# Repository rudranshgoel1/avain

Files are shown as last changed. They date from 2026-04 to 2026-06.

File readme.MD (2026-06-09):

# Avain
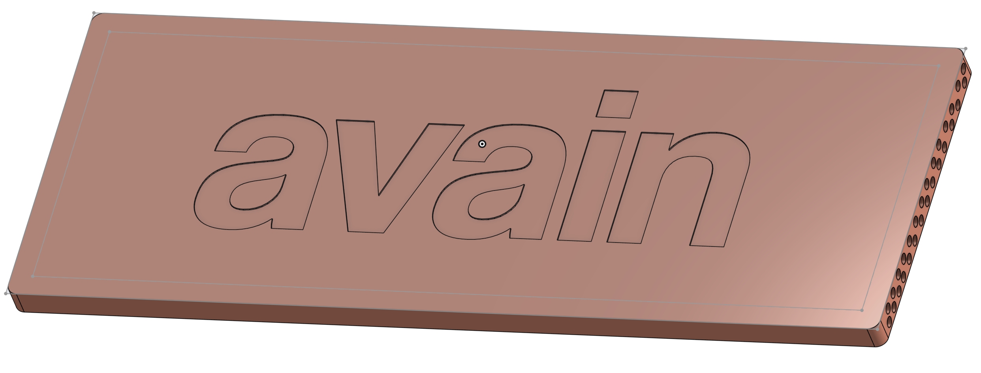
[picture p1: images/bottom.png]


### Why did I make it?
No specific reason tbh. But, another keyboard I made ([Clavis](https://github.com/rudranshgoel1/clavis)) was a 60%, I lowk wanted an 80% keyboard so I made it.

### What was the hardest part about this ?
Hardest part was actually finding time to make this.

Features:

- RotaryEncoder for Volume Control
- 87 keys (Base + Fn keys + arrow keys + 6 extra keys for home/pg up down and other)
- Raspberry Pi Pico
- Customised layout
- KMK firmware
- Avain Branded PCB
- Custom case

### Schematic
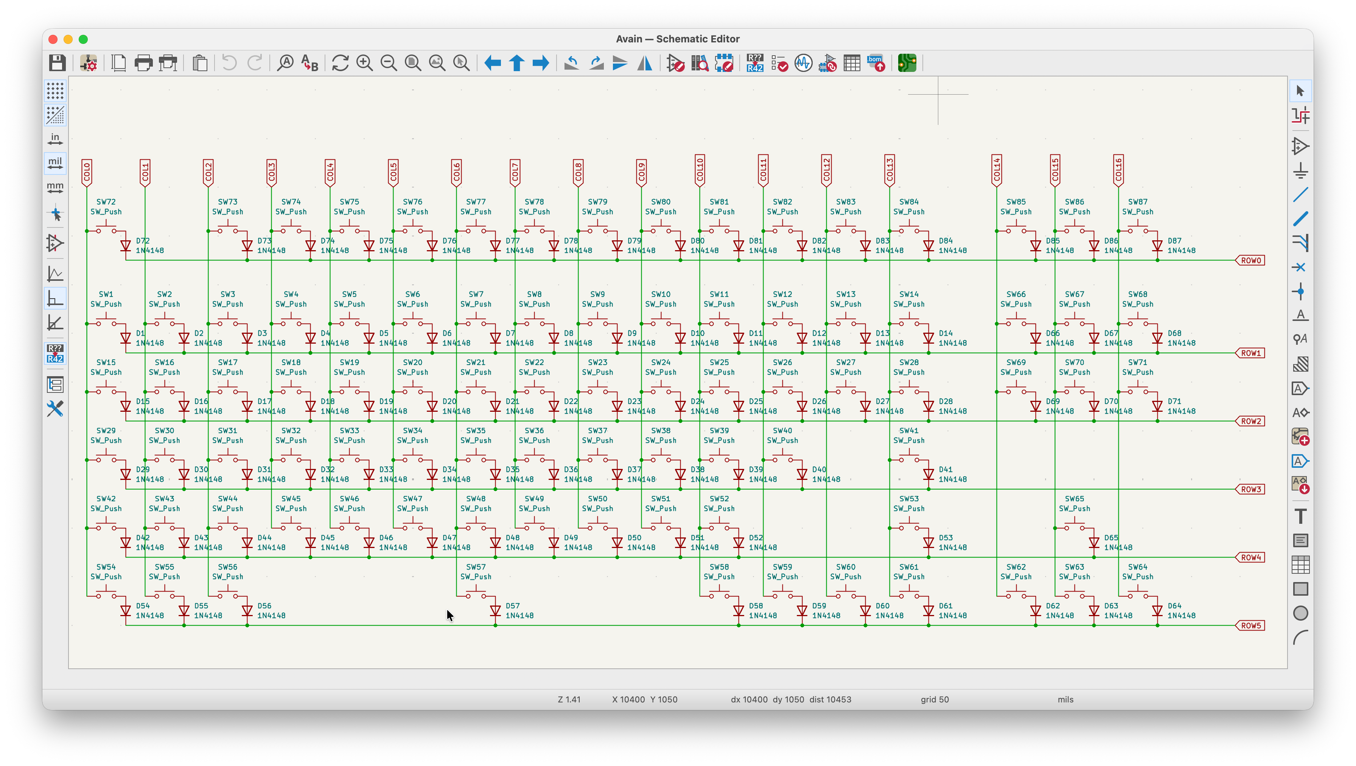
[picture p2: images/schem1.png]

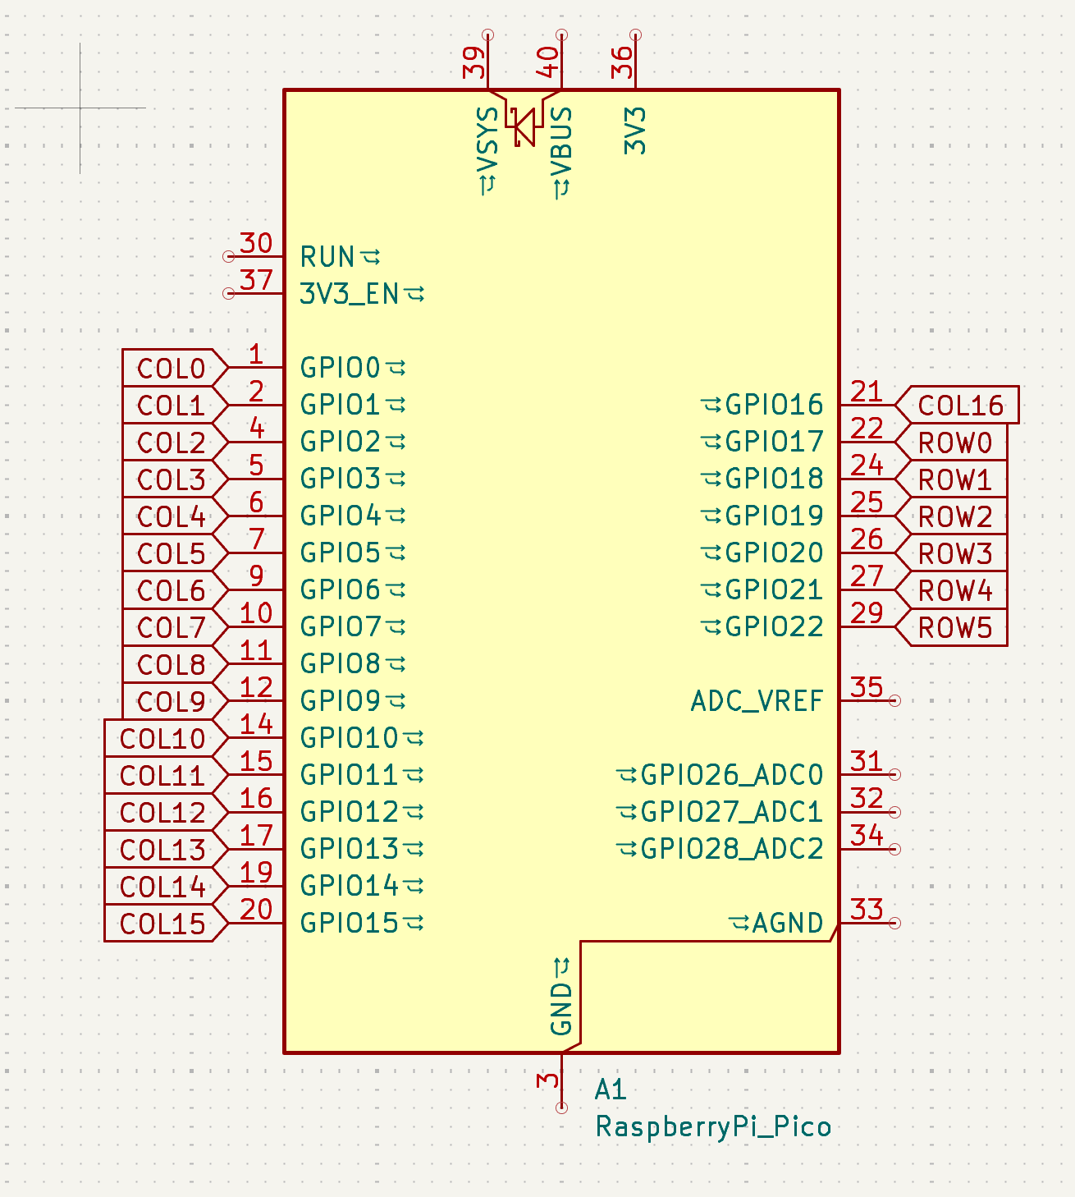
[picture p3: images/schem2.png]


### PCB 
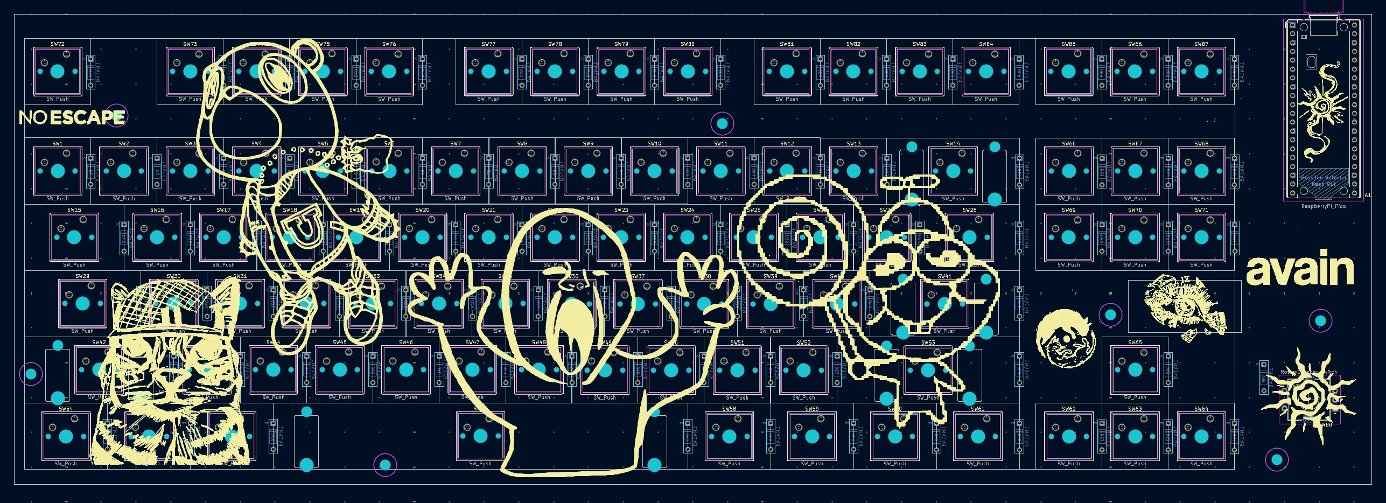
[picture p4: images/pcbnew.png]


### Case



- Side

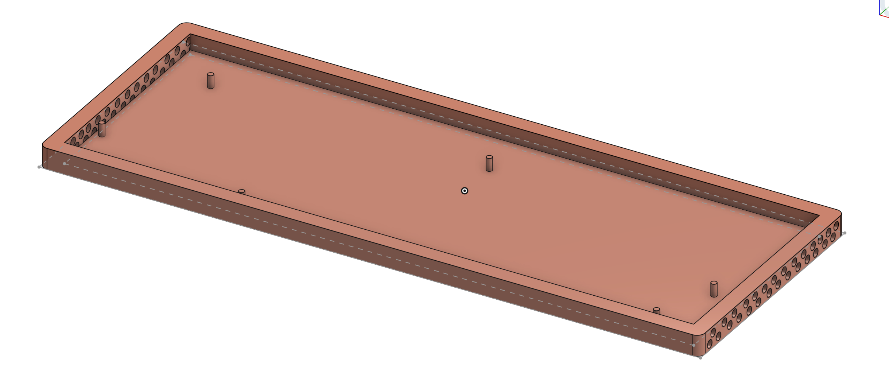
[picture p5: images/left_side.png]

I made some aesthetic for Avain. Like I have added holes on all the sides to make it look more good

### 3D view of all parts 
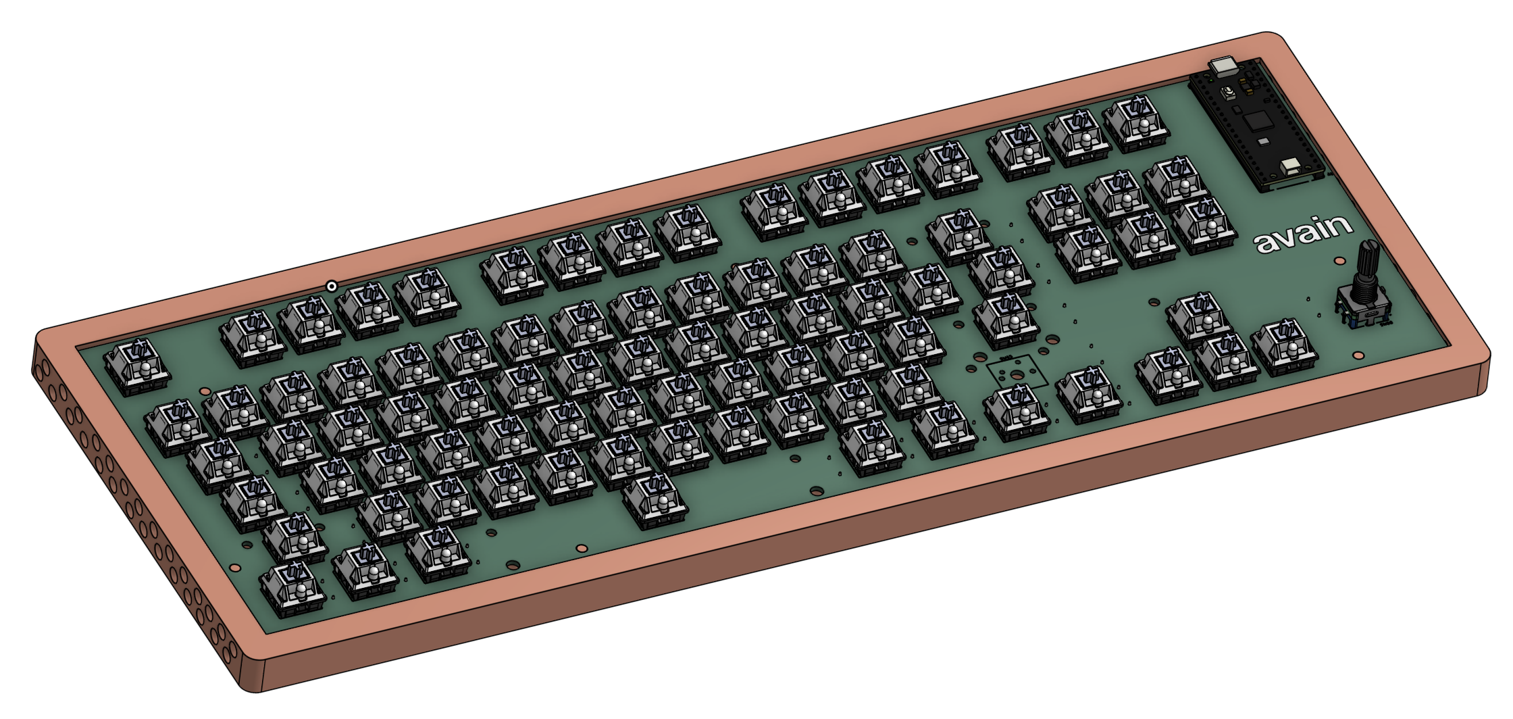
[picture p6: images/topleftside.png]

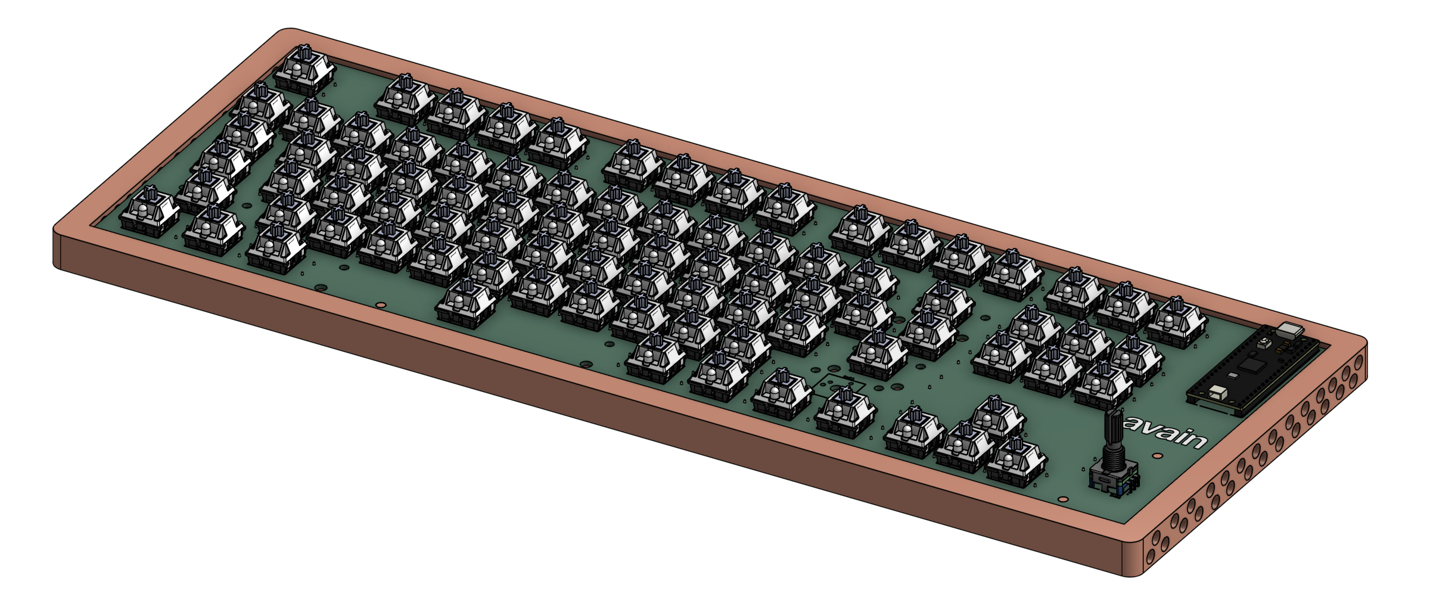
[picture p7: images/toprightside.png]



link to full 3d thing-
https://cad.onshape.com/documents/6774359217ff8c97b90facb7/w/2137304fb52ca582983570b9/e/130904d3ca2552892ee4c097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

A special thanks to Anay and Aditya ( once again ) who are helping me still to make my projects better. Love them so much!

|Name |Purpose |Quantity|Total Cost (INR)|Total Cost (USD)|Link |Distributor |
|---|---|---|---|---|---|---|
|Akko Creamy Cyan Switch |Switches for the keyboard |87 |₹2,598.00 |$28.06 |https://stackskb.com/store/akko-creamy-cyan-switch-pack-of-45-pre-order/ |StacksKB |
|Black Gray Yellow Cherry Doubleshot PBT Keycaps |Keycaps for the keyboard |1 |₹1,399.00 |$15.11 |https://curiositycaps.in/products/black-gray-yellow-cherry-doubleshot-pbt-keycaps|Curiosity Caps|
|Durock Smokey Screw-In Stabilizers V2 (4+1 w/ 6.25u spacebar)|Stabilizers for longer keys |1 |₹1,595.00 |$17.22 |https://stackskb.com/store/durock-smokey-screw-in-stabilizers-v2/ |StacksKB |
|EC11 10K Rotary Encoder |RotaryEncoder for Volume Control|1 |N/A |N/A |Self Sourced |Amazon |
|Raspberry Pi Pico |MCU for the keyboard |1 |₹859.00 |$9.01 |https://www.amazon.in/gp/product/B08WPNM7JB |Amazon |
|1N4148 Diodes |Diodes for the switches |1 |₹149.00 |$1.61 |https://www.amazon.in/gp/product/B084ZP5BJ3 |Amazon |
|PCB |Main PCB of the keyboard |5 |₹3,268.47 |$34.23 |https://jlcpcb.com/ |JLCPCB |
|Case |Case for the keyboard |1 |₹500.00 |$5.40 |Print Legion |Print Legion  |
| | | | | | | |
| | | | | | | |
| | | |₹10,368.47 |109.03 | | |

## Shipping
Amazon + StacksKB = ~$3
Printing Legion = ~$5

Total Shipping = $8

## Total Pricing
The total price comes out to be 10,368.47 INR ($109.03)
Total Shipping = $8

Price After Shipping - 11,175 INR ($117.03)

The pricing might slightly vary due to flash sales, and dollar market trends.

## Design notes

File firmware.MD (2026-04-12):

## Flashing and Configuring the Keyboard

Steps to install the firmware and configure the keyboard:

### 1. Downloading the Repository
Download or clone this repository to your computer.
https://github.com/rudranshgoel1/avain.git

### 2. Enter Boot Mode on the Pico
1. Unplug the Raspberry Pi Pico from your computer.
2. Hold down the **BOOTSEL** button on the Pico.
3. While holding the button, plug the Pico into your computer using a USB cable.
4. The computer will detect a new drive named **RPI-RP2**.

### 3. Flash CircuitPython
1. Download the latest CircuitPython `.uf2` for the Raspberry Pi Pico from [circuitpython.org](https://circuitpython.org/board/raspberry_pi_pico/).
2. Drag and drop the `.uf2` file onto the **RPI-RP2** drive.

Once the file finishes copying, the Pico will reboot automatically and appear as a new drive named **CIRCUITPY**.

### 4. Install KMK and the Keymap
1. Download KMK from [kmkfw.io](https://kmkfw.io) and copy the `kmk/` folder to the root of **CIRCUITPY**.
2. Copy `main.py` from this repository to the root of **CIRCUITPY**.

Your drive should look like this:
```
CIRCUITPY/
├── main.py
└── kmk/
```

### 5. Configure the Keymap
The keyboard layout can be customised in `main.py`.

Open the file in a text editor and edit the keymap section to match the layout you want.
After saving the file, the keyboard will automatically reload with the new configuration.

### 6. Test the Keyboard
Unplug and reconnect the keyboard, open a text editor, and press some keys to make sure everything works.

## KABOOM!
IT'S DONE!!!

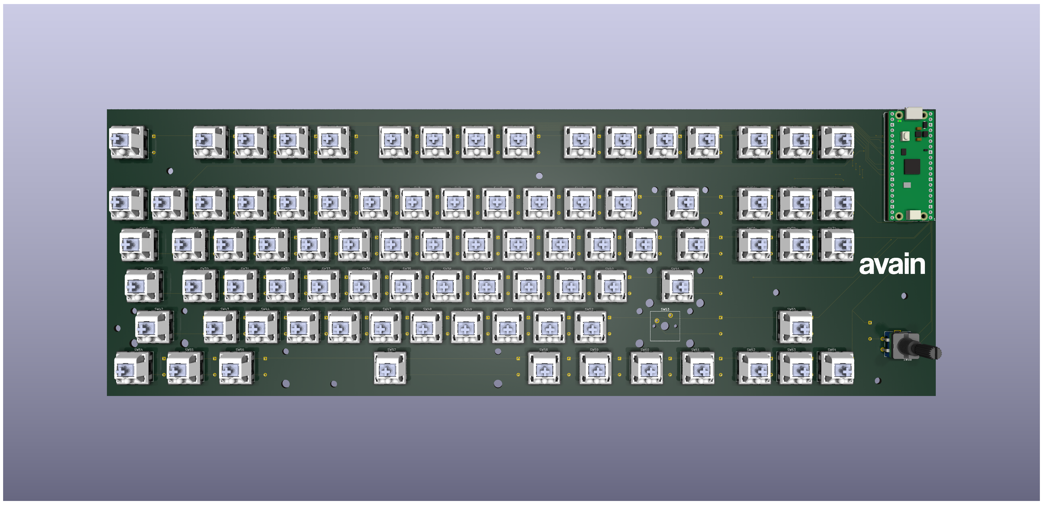
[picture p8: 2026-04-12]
images/topview3d.png

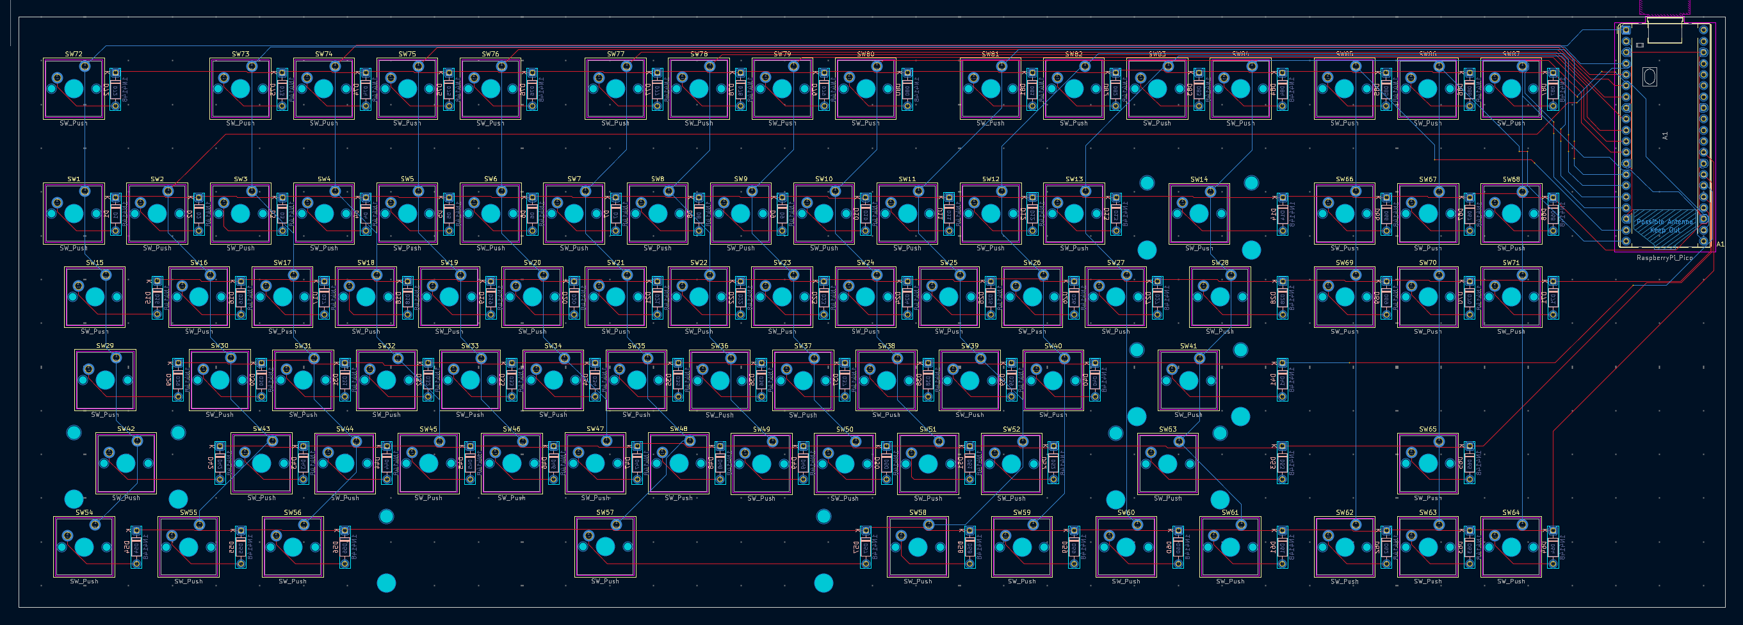
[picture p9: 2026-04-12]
images/pcb.png

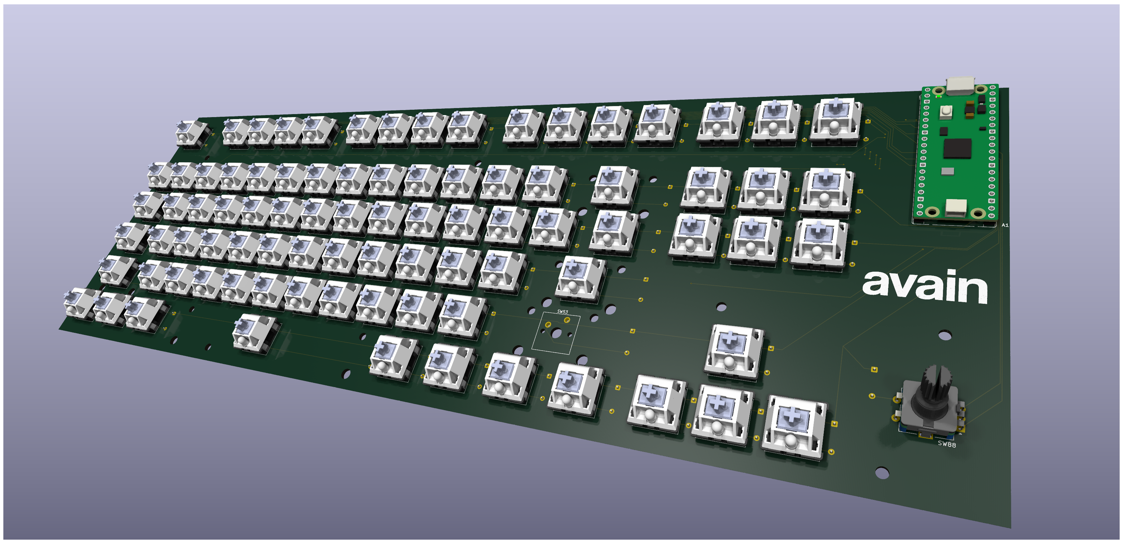
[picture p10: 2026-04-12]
images/sideview3d.png

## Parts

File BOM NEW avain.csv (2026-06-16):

Name | Purpose | Quantity | Total Cost (INR) | Total Cost (USD) | Link | Distributor
Akko Creamy Cyan Switch | Switches for the keyboard | 87 | _2,598.00 | $28.06 | https://stackskb.com/store/akko-creamy-cyan-switch-pack-of-45-pre-order/ | StacksKB
Black Gray Yellow Cherry Doubleshot PBT Keycaps | Keycaps for the keyboard | 1 | _1,399.00 | $15.11 | https://curiositycaps.in/products/black-gray-yellow-cherry-doubleshot-pbt-keycaps | Curiosity Caps
Durock Smokey Screw-In Stabilizers V2 (4+1 w/ 6.25u spacebar) | Stabilizers for longer keys | 1 | _1,595.00 | $17.22 | https://stackskb.com/store/durock-smokey-screw-in-stabilizers-v2/ | StacksKB
EC11 10K Rotary Encoder | RotaryEncoder for Volume Control | 1 | N/A | N/A | Self Sourced | Amazon
Raspberry Pi Pico | MCU for the keyboard | 1 | _859.00 | $9.01 | https://www.amazon.in/gp/product/B08WPNM7JB | Amazon
1N4148 Diodes | Diodes for the switches | 1 | _149.00 | $1.61 | https://www.amazon.in/gp/product/B084ZP5BJ3 | Amazon
PCB | Main PCB of the keyboard | 5 | _3,268.47 | $34.23 | https://jlcpcb.com/ | JLCPCB
Case | Case for the keyboard | 1 | _500.00 | $5.40 | Print Legion | Print Legion
 |  |  | _10,368.47 | 109.03

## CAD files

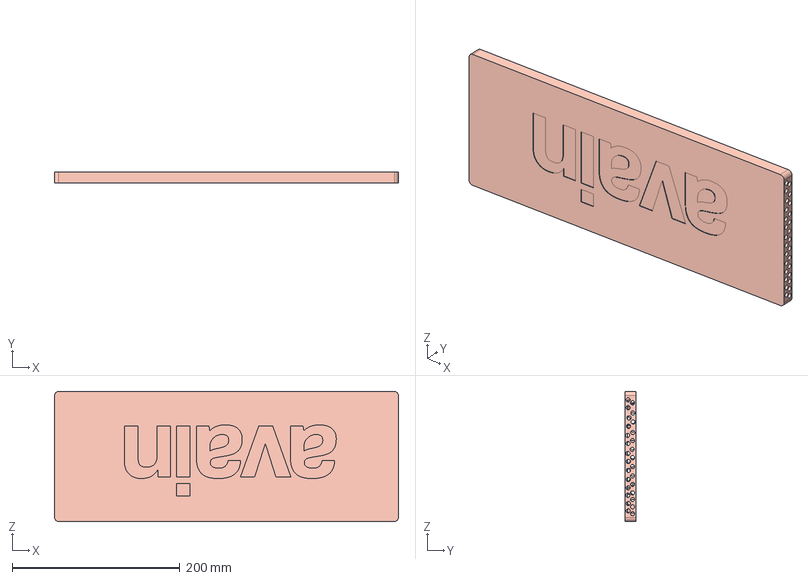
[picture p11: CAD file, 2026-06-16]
CAD/Case/Full Case.step
410.0 x 13.0 x 155.0 mm

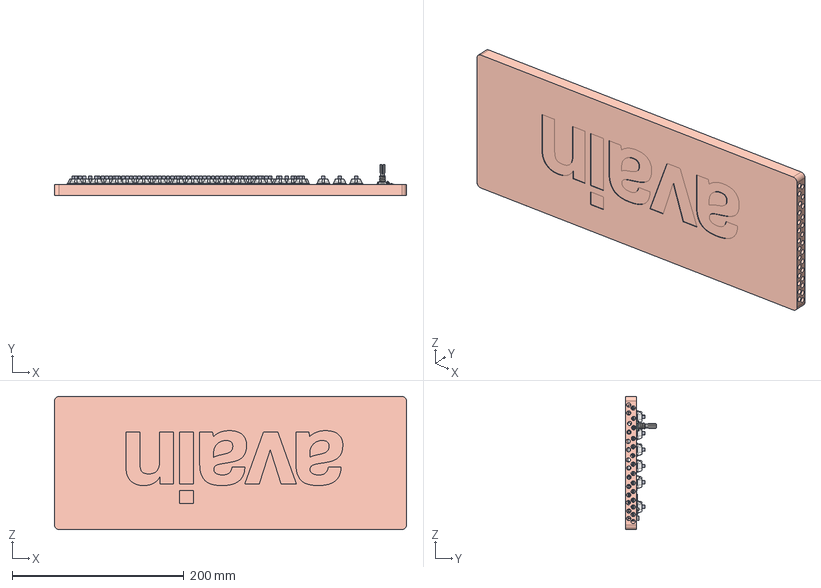
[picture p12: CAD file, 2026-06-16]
CAD/Full Avain Assembly.step
410.0 x 36.1 x 155.0 mm
Avain_silkscreen x 885
D_DO-35_SOD27_P7.62mm_Horizontal x 176
EC11_Rotary_Encoder_Switched x 10
Avain_PCB
Pieza5^Cherry MX x 86
Top x 86
Led 3mm_trans x 172
Pin2 x 86
Pulsador x 86
Pin1 x 86
Bottom x 86
RaspberryPi_Pico_H_Module_KiCad
RaspberryPi_Pico_Header_DIP-40_H2.54mm_KiCad

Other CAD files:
PRODUCTION/CAD/Case/AvainCase.step
CAD/Case/Full Case.stl
PRODUCTION/CAD/Case/AvainCase.stl

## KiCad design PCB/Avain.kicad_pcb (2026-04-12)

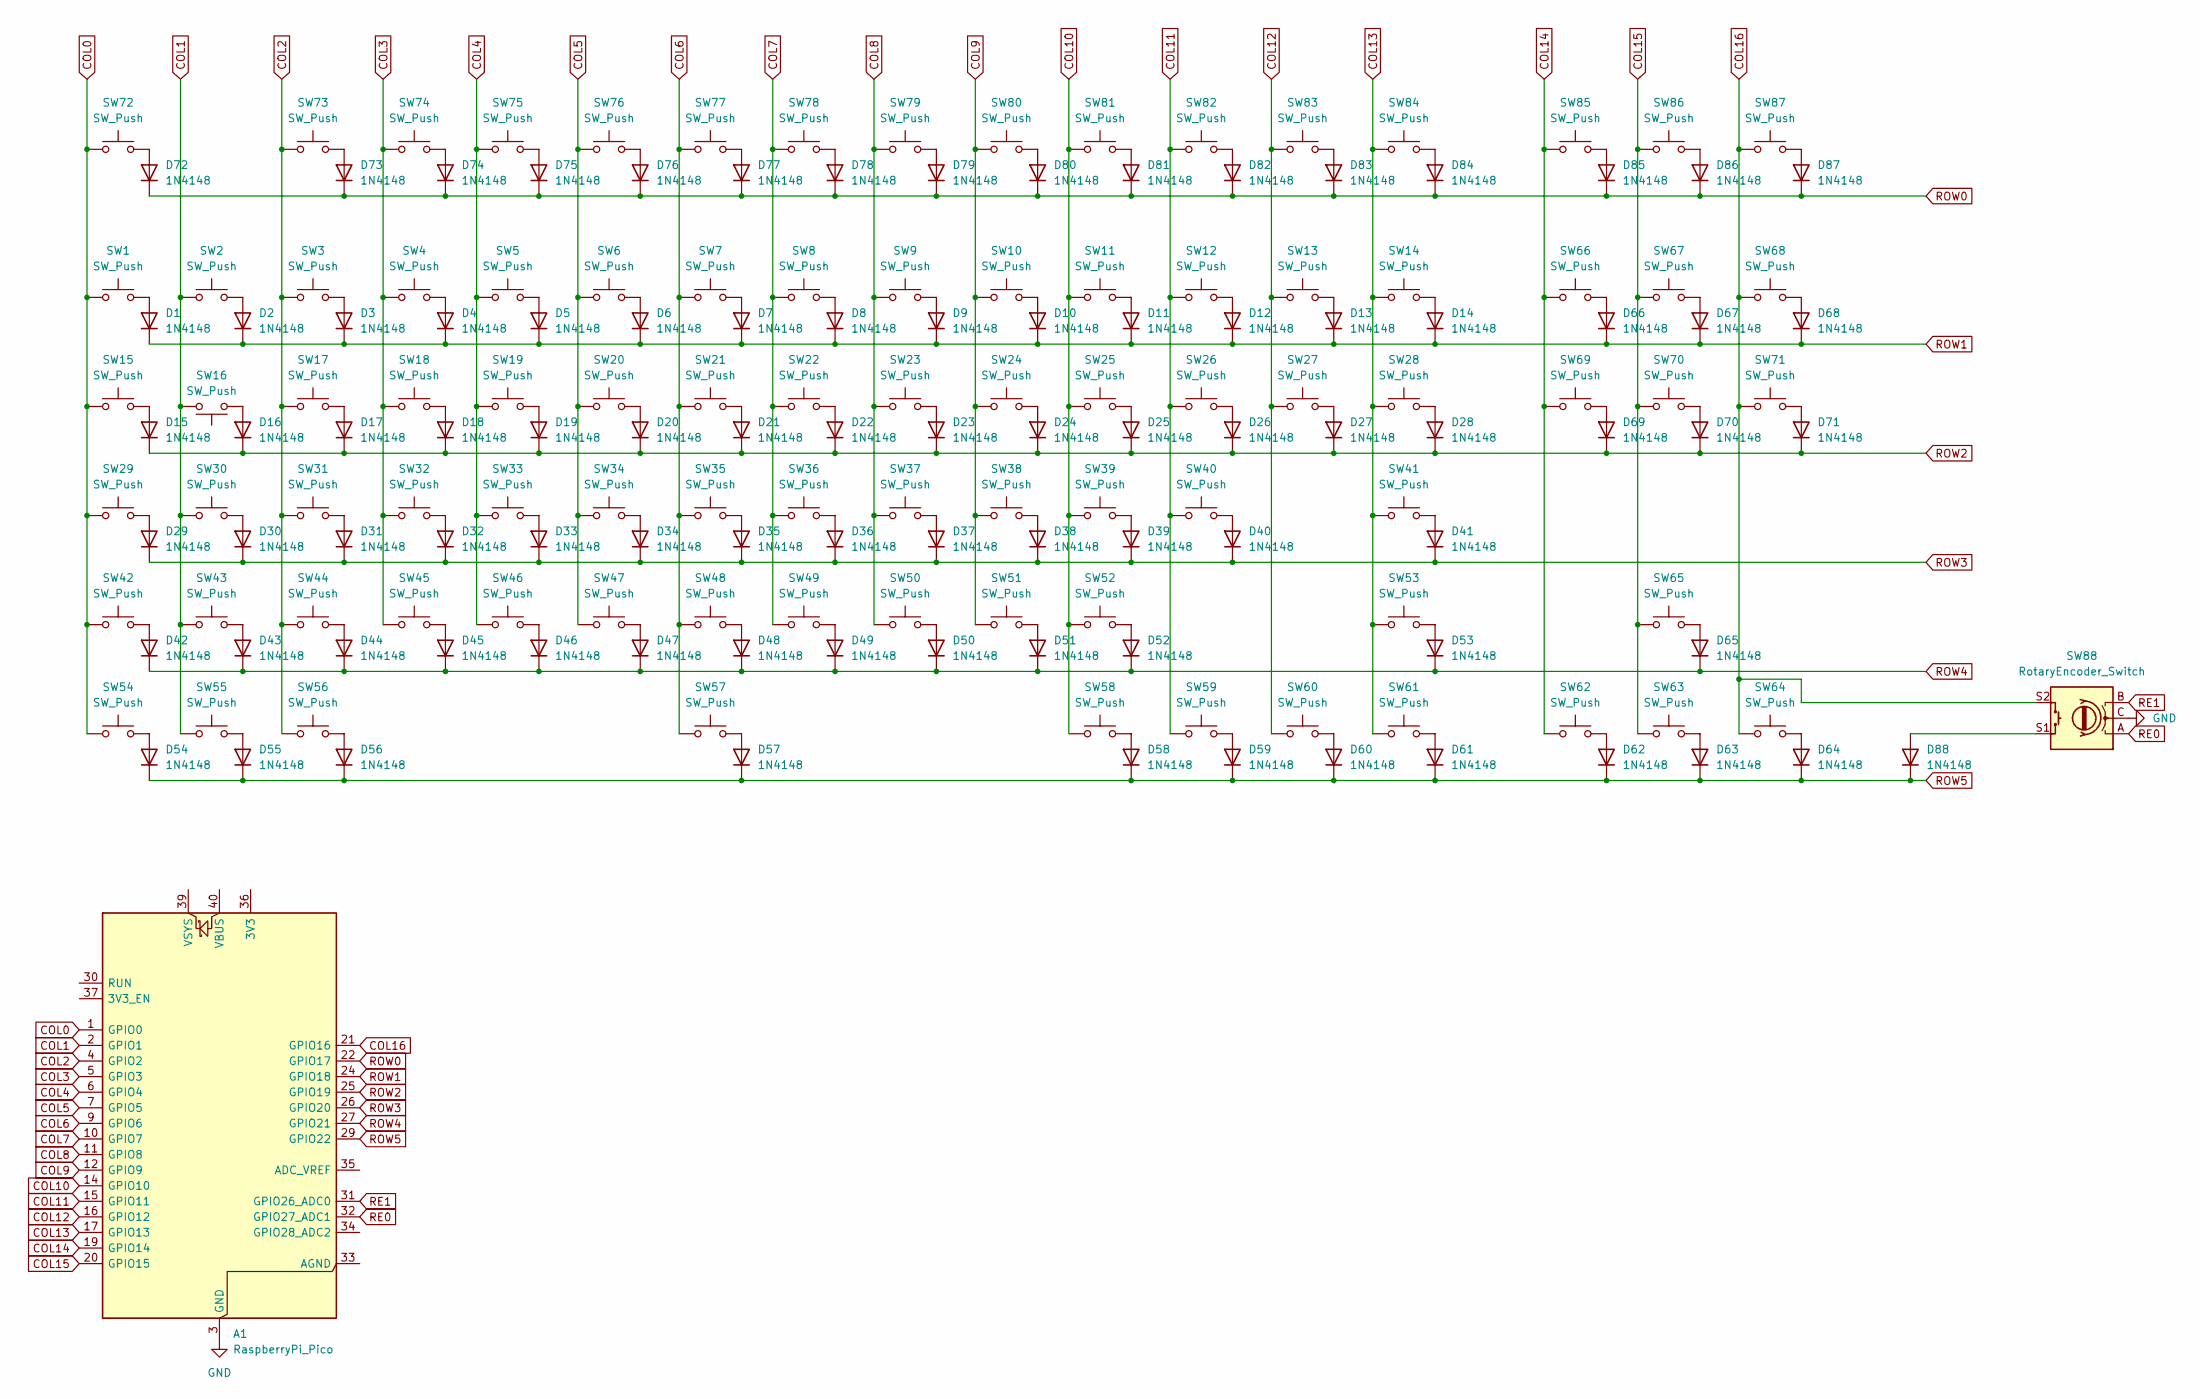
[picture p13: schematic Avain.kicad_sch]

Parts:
A1: RaspberryPi_Pico; RaspberryPi_Pico_Common_THT
D1, D2, D3, D4, D5, D6, D7, D8, D9, D10, D11, D12, D13, D14, D15, D16, D17, D18, D19, D20, D21, D22, D23, D24, D25, D26, D27, D28, D29, D30, D31, D32, D33, D34, D35, D36, D37, D38, D39, D40, D41, D42, D43, D44, D45, D46, D47, D48, D49, D50, D51, D52, D53, D54, D55, D56, D57, D58, D59, D60, D61, D62, D63, D64, D65, D66, D67, D68, D69, D70, D71, D72, D73, D74, D75, D76, D77, D78, D79, D80, D81, D82, D83, D84, D85, D86, D87, D88: 1N4148; D_DO-35_SOD27_P7.62mm_Horizontal
SW1, SW2, SW3, SW4, SW5, SW6, SW7, SW8, SW9, SW10, SW11, SW12, SW13, SW16, SW17, SW18, SW19, SW20, SW21, SW22, SW23, SW24, SW25, SW26, SW27, SW30, SW31, SW32, SW33, SW34, SW35, SW36, SW37, SW38, SW39, SW40, SW43, SW44, SW45, SW46, SW47, SW48, SW49, SW50, SW51, SW52, SW62, SW63, SW64, SW65, SW66, SW67, SW68, SW69, SW70, SW71, SW72, SW73, SW74, SW75, SW76, SW77, SW78, SW79, SW80, SW81, SW82, SW83, SW84, SW85, SW86, SW87: SW_Push; SW_Cherry_MX_1.00u_PCB
SW14: SW_Push; SW_Cherry_MX_2.00u_PCB
SW15, SW28: SW_Push; SW_Cherry_MX_1.50u_PCB
SW29: SW_Push; SW_Cherry_MX_1.75u_PCB
SW41, SW42: SW_Push; SW_Cherry_MX_2.25u_PCB
SW53: SW_Push; SW_Cherry_MX_2.75u_PCB
SW54, SW55, SW56, SW58, SW59, SW60, SW61: SW_Push; SW_Cherry_MX_1.25u_PCB
SW57: SW_Push; SW_Cherry_MX_6.25u_PCB
SW88: RotaryEncoder_Switch; RotaryEncoder_Alps_EC11E-Switch_Vertical_H20mm

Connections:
COL0: A1.1 (GPIO0), SW1.1, SW15.1, SW29.1, SW42.1, SW54.1, SW72.1
COL1: A1.2 (GPIO1), SW2.1, SW16.1, SW30.1, SW43.1, SW55.1
COL2: A1.4 (GPIO2), SW3.1, SW17.1, SW31.1, SW44.1, SW56.1, SW73.1
COL3: A1.5 (GPIO3), SW4.1, SW18.1, SW32.1, SW45.1, SW74.1
COL4: A1.6 (GPIO4), SW5.1, SW19.1, SW33.1, SW46.1, SW75.1
COL5: A1.7 (GPIO5), SW6.1, SW20.1, SW34.1, SW47.1, SW76.1
COL6: A1.9 (GPIO6), SW7.1, SW21.1, SW35.1, SW48.1, SW57.1, SW77.1
COL7: A1.10 (GPIO7), SW8.1, SW22.1, SW36.1, SW49.1, SW78.1
COL8: A1.11 (GPIO8), SW9.1, SW23.1, SW37.1, SW50.1, SW79.1
COL9: A1.12 (GPIO9), SW10.1, SW24.1, SW38.1, SW51.1, SW80.1
COL10: A1.14 (GPIO10), SW11.1, SW25.1, SW39.1, SW52.1, SW58.1, SW81.1
COL11: A1.15 (GPIO11), SW12.1, SW26.1, SW40.1, SW59.1, SW82.1
COL12: A1.16 (GPIO12), SW13.1, SW27.1, SW60.1, SW83.1
COL13: A1.17 (GPIO13), SW14.1, SW28.1, SW41.1, SW53.1, SW61.1, SW84.1
COL14: A1.19 (GPIO14), SW62.1, SW66.1, SW69.1, SW85.1
COL15: A1.20 (GPIO15), SW63.1, SW65.1, SW67.1, SW70.1, SW86.1
COL16: A1.21 (GPIO16), SW64.1, SW68.1, SW71.1, SW87.1, SW88.S2
GND: A1.3 (GND), A1.8 (GND), A1.13 (GND), A1.18 (GND), A1.23 (GND), A1.28 (GND), A1.38 (GND), SW88.C
unnamed: D1.2 (A), SW1.2
unnamed: D2.2 (A), SW2.2
unnamed: D3.2 (A), SW3.2
unnamed: D4.2 (A), SW4.2
unnamed: D5.2 (A), SW5.2
unnamed: D6.2 (A), SW6.2
unnamed: D7.2 (A), SW7.2
unnamed: D8.2 (A), SW8.2
unnamed: D9.2 (A), SW9.2
unnamed: D10.2 (A), SW10.2
unnamed: D11.2 (A), SW11.2
unnamed: D12.2 (A), SW12.2
unnamed: D13.2 (A), SW13.2
unnamed: D14.2 (A), SW14.2
unnamed: D15.2 (A), SW15.2
unnamed: D16.2 (A), SW16.2
unnamed: D17.2 (A), SW17.2
unnamed: D18.2 (A), SW18.2
unnamed: D19.2 (A), SW19.2
unnamed: D20.2 (A), SW20.2
unnamed: D21.2 (A), SW21.2
unnamed: D22.2 (A), SW22.2
unnamed: D23.2 (A), SW23.2
unnamed: D24.2 (A), SW24.2
unnamed: D25.2 (A), SW25.2
unnamed: D26.2 (A), SW26.2
unnamed: D27.2 (A), SW27.2
unnamed: D28.2 (A), SW28.2
unnamed: D29.2 (A), SW29.2
unnamed: D30.2 (A), SW30.2
unnamed: D31.2 (A), SW31.2
unnamed: D32.2 (A), SW32.2
unnamed: D33.2 (A), SW33.2
unnamed: D34.2 (A), SW34.2
unnamed: D35.2 (A), SW35.2
unnamed: D36.2 (A), SW36.2
unnamed: D37.2 (A), SW37.2
unnamed: D38.2 (A), SW38.2
unnamed: D39.2 (A), SW39.2
unnamed: D40.2 (A), SW40.2
unnamed: D41.2 (A), SW41.2
unnamed: D42.2 (A), SW42.2
unnamed: D43.2 (A), SW43.2
unnamed: D44.2 (A), SW44.2
unnamed: D45.2 (A), SW45.2
unnamed: D46.2 (A), SW46.2
unnamed: D47.2 (A), SW47.2
unnamed: D48.2 (A), SW48.2
unnamed: D49.2 (A), SW49.2
unnamed: D50.2 (A), SW50.2
unnamed: D51.2 (A), SW51.2
unnamed: D52.2 (A), SW52.2
unnamed: D53.2 (A), SW53.2
unnamed: D54.2 (A), SW54.2
unnamed: D55.2 (A), SW55.2
unnamed: D56.2 (A), SW56.2
unnamed: D57.2 (A), SW57.2
unnamed: D58.2 (A), SW58.2
unnamed: D59.2 (A), SW59.2
unnamed: D60.2 (A), SW60.2
unnamed: D61.2 (A), SW61.2
unnamed: D62.2 (A), SW62.2
unnamed: D63.2 (A), SW63.2
unnamed: D64.2 (A), SW64.2
unnamed: D65.2 (A), SW65.2
unnamed: D66.2 (A), SW66.2
unnamed: D67.2 (A), SW67.2
unnamed: D68.2 (A), SW68.2
unnamed: D69.2 (A), SW69.2
unnamed: D70.2 (A), SW70.2
unnamed: D71.2 (A), SW71.2
unnamed: D72.2 (A), SW72.2
unnamed: D73.2 (A), SW73.2
unnamed: D74.2 (A), SW74.2
unnamed: D75.2 (A), SW75.2
unnamed: D76.2 (A), SW76.2
unnamed: D77.2 (A), SW77.2
unnamed: D78.2 (A), SW78.2
unnamed: D79.2 (A), SW79.2
unnamed: D80.2 (A), SW80.2
unnamed: D81.2 (A), SW81.2
unnamed: D82.2 (A), SW82.2
unnamed: D83.2 (A), SW83.2
unnamed: D84.2 (A), SW84.2
unnamed: D85.2 (A), SW85.2
unnamed: D86.2 (A), SW86.2
unnamed: D87.2 (A), SW87.2
unnamed: D88.2 (A), SW88.S1
RE0: A1.32 (GPIO27_ADC1), SW88.A
RE1: A1.31 (GPIO26_ADC0), SW88.B
ROW0: A1.22 (GPIO17), D72.1 (K), D73.1 (K), D74.1 (K), D75.1 (K), D76.1 (K), D77.1 (K), D78.1 (K), D79.1 (K), D80.1 (K), D81.1 (K), D82.1 (K), D83.1 (K), D84.1 (K), D85.1 (K), D86.1 (K), D87.1 (K)
ROW1: A1.24 (GPIO18), D1.1 (K), D2.1 (K), D3.1 (K), D4.1 (K), D5.1 (K), D6.1 (K), D7.1 (K), D8.1 (K), D9.1 (K), D10.1 (K), D11.1 (K), D12.1 (K), D13.1 (K), D14.1 (K), D66.1 (K), D67.1 (K), D68.1 (K)
ROW2: A1.25 (GPIO19), D15.1 (K), D16.1 (K), D17.1 (K), D18.1 (K), D19.1 (K), D20.1 (K), D21.1 (K), D22.1 (K), D23.1 (K), D24.1 (K), D25.1 (K), D26.1 (K), D27.1 (K), D28.1 (K), D69.1 (K), D70.1 (K), D71.1 (K)
ROW3: A1.26 (GPIO20), D29.1 (K), D30.1 (K), D31.1 (K), D32.1 (K), D33.1 (K), D34.1 (K), D35.1 (K), D36.1 (K), D37.1 (K), D38.1 (K), D39.1 (K), D40.1 (K), D41.1 (K)
ROW4: A1.27 (GPIO21), D42.1 (K), D43.1 (K), D44.1 (K), D45.1 (K), D46.1 (K), D47.1 (K), D48.1 (K), D49.1 (K), D50.1 (K), D51.1 (K), D52.1 (K), D53.1 (K), D65.1 (K)
ROW5: A1.29 (GPIO22), D54.1 (K), D55.1 (K), D56.1 (K), D57.1 (K), D58.1 (K), D59.1 (K), D60.1 (K), D61.1 (K), D62.1 (K), D63.1 (K), D64.1 (K), D88.1 (K)

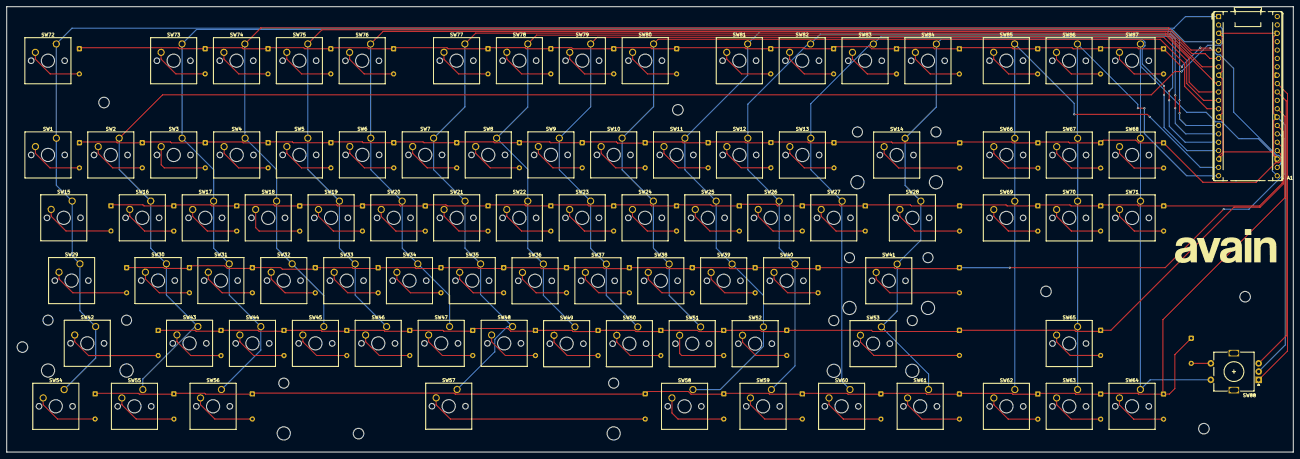
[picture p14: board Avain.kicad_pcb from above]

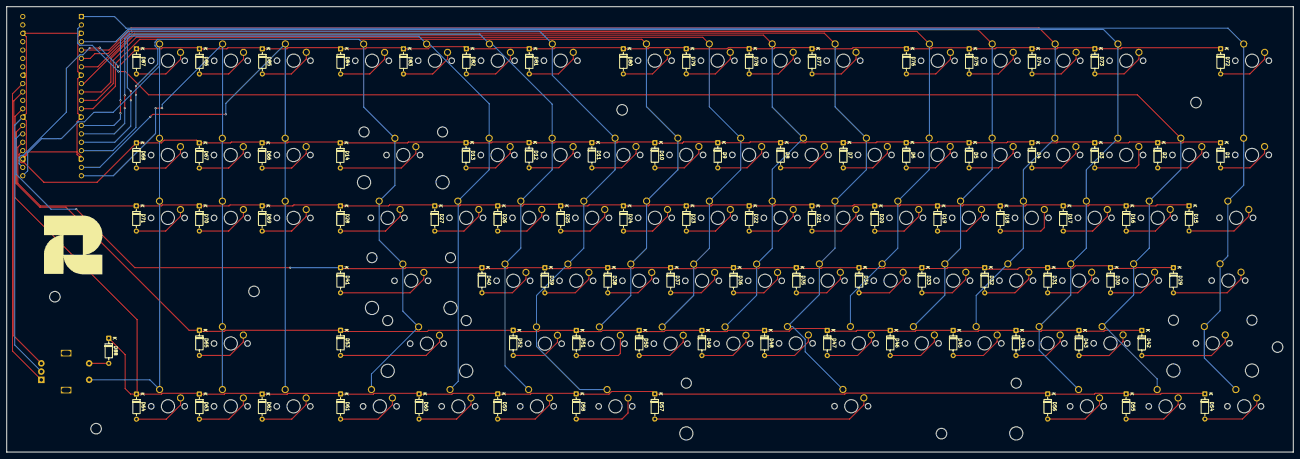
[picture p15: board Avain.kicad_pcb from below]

Board: 2 copper layers, 390.0 x 135.0 mm, 177 parts (88 on the bottom side), 114 nets.

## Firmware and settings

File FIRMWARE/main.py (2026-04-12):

import board
from kb import keyboard, encoder_handler
from kmk.keys import KC
from kmk.modules.layers import Layers

layers_mod = Layers()
keyboard.modules.append(layers_mod)

_______ = KC.TRNS  # transparent — falls through to layer below
XXXXXXX = KC.NO    # blocked — does nothing

BASE = 0
FN   = 1

keyboard.keymap = [

    [
        KC.ESC,  KC.F1,   KC.F2,   KC.F3,   KC.F4,   KC.F5,   KC.F6,   KC.F7,
        KC.F8,   KC.F9,   KC.F10,  KC.F11,  KC.F12,  KC.PSCR, KC.SLCK, KC.PAUS,
        XXXXXXX,

        KC.GRV,  KC.N1,   KC.N2,   KC.N3,   KC.N4,   KC.N5,   KC.N6,   KC.N7,
        KC.N8,   KC.N9,   KC.N0,   KC.MINS, KC.EQL,  KC.BSPC, KC.INS,  KC.HOME,
        KC.PGUP,

        KC.TAB,  KC.Q,    KC.W,    KC.E,    KC.R,    KC.T,    KC.Y,    KC.U,
        KC.I,    KC.O,    KC.P,    KC.LBRC, KC.RBRC, KC.BSLS, KC.DEL,  KC.END,
        KC.PGDN,

        KC.CAPS, KC.A,    KC.S,    KC.D,    KC.F,    KC.G,    KC.H,    KC.J,
        KC.K,    KC.L,    KC.SCLN, KC.QUOT, KC.ENT,  XXXXXXX, XXXXXXX, XXXXXXX,
        XXXXXXX,

        KC.LSFT, KC.Z,    KC.X,    KC.C,    KC.V,    KC.B,    KC.N,    KC.M,
        KC.COMM, KC.DOT,  KC.SLSH, KC.RSFT, XXXXXXX, XXXXXXX, XXXXXXX, KC.UP,
        XXXXXXX,

        KC.LCTL, KC.LGUI, KC.LALT, XXXXXXX, XXXXXXX, KC.SPC,  XXXXXXX, KC.RALT,
        KC.MO(FN), KC.RCTL, XXXXXXX, XXXXXXX, KC.LEFT, KC.DOWN, KC.RGHT,
        XXXXXXX,
        KC.MUTE,  
    ],

    [
        _______, KC.MPLY, KC.MSTP, KC.MPRV, KC.MNXT, KC.MUTE, KC.VOLD, KC.VOLU,
        KC.BRID, KC.BRIU, _______, _______, _______, _______, _______, _______,
        XXXXXXX,

        _______, _______, _______, _______, _______, _______, _______, _______,
        _______, _______, _______, _______, _______, KC.DEL,  _______, _______,
        _______,

        _______, _______, _______, _______, _______, _______, _______, _______,
        _______, _______, _______, _______, _______, _______, _______, _______,
        _______,

        _______, _______, _______, _______, _______, _______, _______, _______,
        _______, _______, _______, _______, _______, XXXXXXX, XXXXXXX, XXXXXXX,
        XXXXXXX,

        _______, _______, _______, _______, _______, _______, _______, _______,
        _______, _______, _______, _______, XXXXXXX, XXXXXXX, XXXXXXX, _______,
        XXXXXXX,

        _______, _______, _______, XXXXXXX, XXXXXXX, _______, XXXXXXX, _______,
        _______, _______, XXXXXXX, XXXXXXX, _______, _______, _______,
        XXXXXXX,
        _______,
    ],
]

encoder_handler.map = [
    # BASE — rotate for volume
    ((KC.VOLD, KC.VOLU),),
    # FN — rotate for track prev/next
    ((KC.MPRV, KC.MNXT),),
]

if __name__ == '__main__':
    keyboard.go()

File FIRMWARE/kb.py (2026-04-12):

import board
from kmk.kmk_keyboard import KMKKeyboard
from kmk.scanners import DiodeOrientation
from kmk.scanners.keypad import MatrixScanner
from kmk.modules.encoder import EncoderHandler

keyboard = KMKKeyboard()

keyboard.matrix = MatrixScanner(
    column_pins=(
        board.GP0,  board.GP1,  board.GP2,  board.GP3,
        board.GP4,  board.GP5,  board.GP6,  board.GP7,
        board.GP8,  board.GP9,  board.GP10, board.GP11,
        board.GP12, board.GP13, board.GP14, board.GP15,
        board.GP16,
    ),
    row_pins=(
        board.GP17, board.GP18, board.GP19,
        board.GP20, board.GP21, board.GP22,
    ),
    diode_orientation=DiodeOrientation.COL2ROW,
)

encoder_handler = EncoderHandler()
encoder_handler.pins = ((board.GP27, board.GP26, None, False),)

keyboard.modules.append(encoder_handler)

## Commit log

2026-04-12 main commit
    [Avain.kicad_pcb, Avain.kicad_sch, AvainCase.step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]
2026-04-12 fix BOM
2026-04-12 added images
    [BOM NEW avain.csv]
2026-04-23 updated bom
    [BOM NEW avain.csv]
2026-04-26 last minute bom update
    [BOM NEW avain.csv]
2026-06-16 added case files
    [AvainCase.step, AvainCase.stl, BOM NEW avain.csv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]
